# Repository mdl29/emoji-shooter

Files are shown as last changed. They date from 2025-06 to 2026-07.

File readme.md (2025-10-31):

# Emoji Shooter

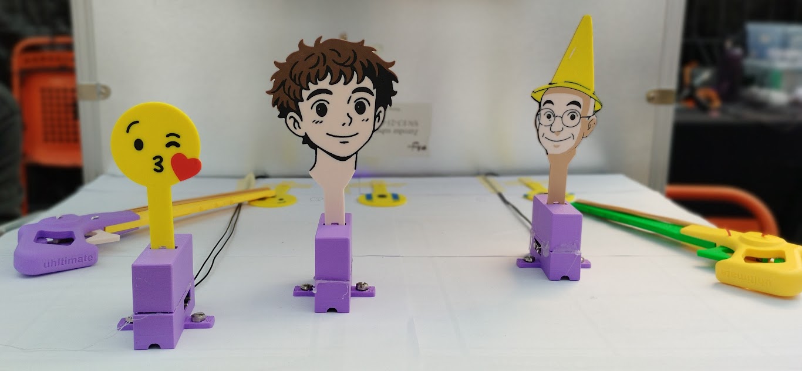
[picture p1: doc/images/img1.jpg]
Image of three targets


## Description
Emoji Shooter is an interactive shooting game. Players use a rubber band gun to shoot at jumping emoji targets. Each target is equipped with a mechanical switch for hit detection, and the game is tracked by an Arduino Uno. A web frontend displays the score and interacts with the hardware via serial communication.

## Features
- Physical emoji targets with mechanical hit detection
- Arduino firmware for real-time target state tracking
- Web frontend for score display and serial connection
- Visual feedback via LEDs on each target base

## Inspirations
- [Rubber Band Gun Model](https://makerworld.com/en/models/56969)
- [Original Jumping Targets](https://www.thingiverse.com/thing:1306585)

## How does it work?
Each emoji target sits on a base with a mechanical switch. When upright, the target presses the switch. A successful hit causes the target to jump or fall, releasing the switch. The Arduino detects this change and updates the game state.

### Sequence:
1. Target is placed upright, pressing the switch.
2. Player shoots a rubber band at the target.
3. Target jumps, releasing the switch.
4. Arduino detects the switch state change and registers a hit.
5. Score is sent to the web frontend and updated.

## Usage

1. Flash the firmware to your Arduino
2. Connect the Arduino to your computer via USB
3. Open the [website](https://mdl29.github.io/emoji-shooter/) in a Chromium browser
4. Connect to the Arduino with the button on top-left
5. Play by shooting at the emoji targets and watch your score update in real time

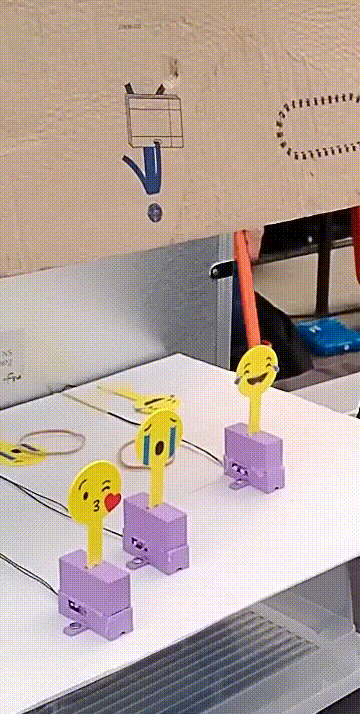
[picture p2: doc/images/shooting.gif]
Demo of a target being shot


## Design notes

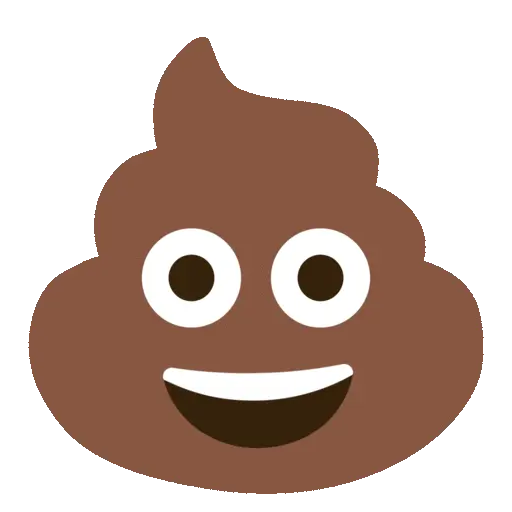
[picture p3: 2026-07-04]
frontend/asset/targets/poop.webp

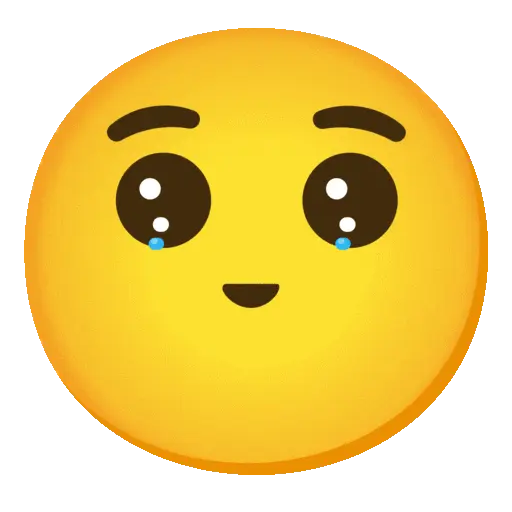
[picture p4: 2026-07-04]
frontend/asset/targets/cry.webp

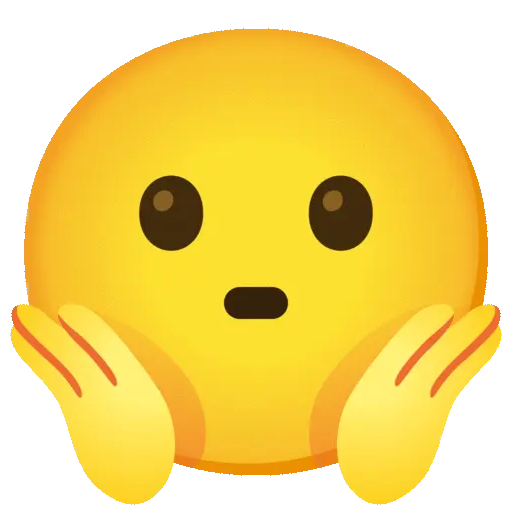
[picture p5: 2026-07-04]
frontend/asset/targets/chocked.webp

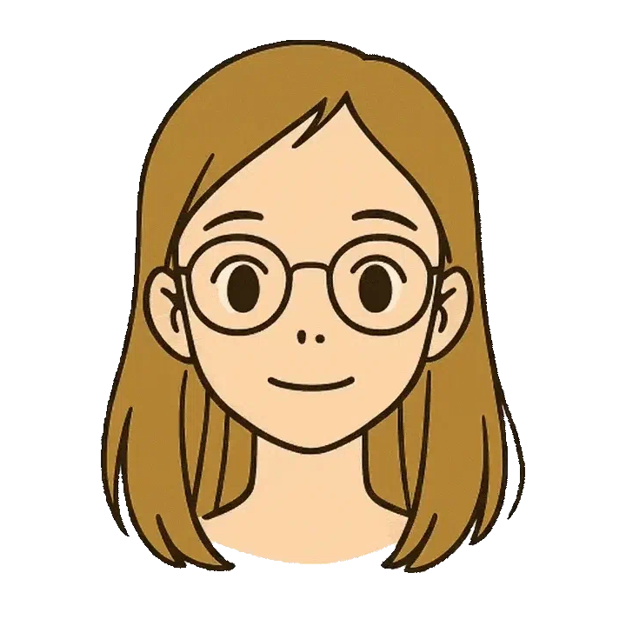
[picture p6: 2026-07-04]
frontend/asset/targets/erell.webp

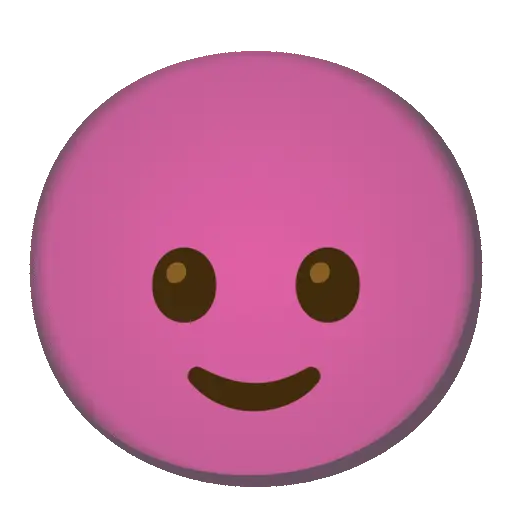
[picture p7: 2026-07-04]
frontend/asset/targets/devil.webp

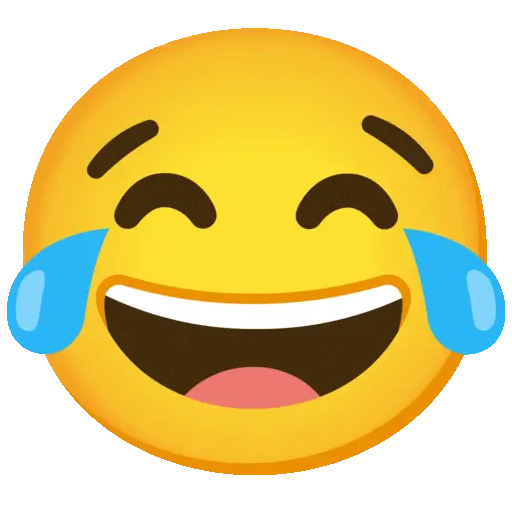
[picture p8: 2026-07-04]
frontend/asset/targets/laugh.webp

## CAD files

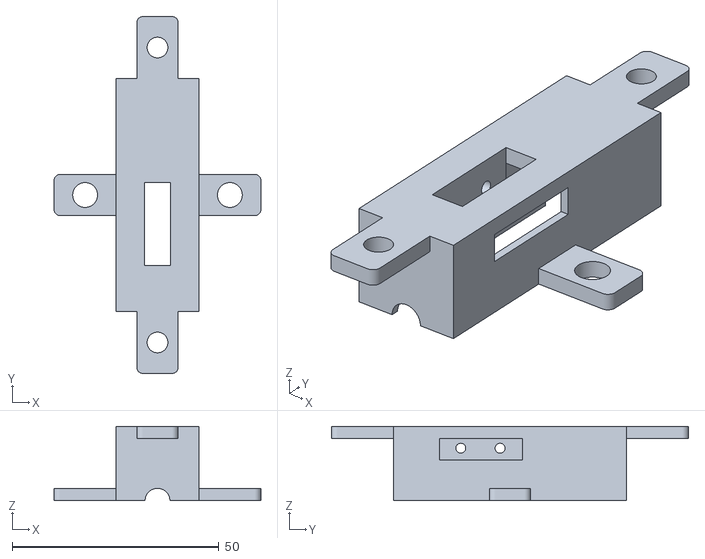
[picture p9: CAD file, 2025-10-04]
3Dparts/bottom-target-jump-base-Body - b3e90a6.stl
50.0 x 86.3 x 18.0

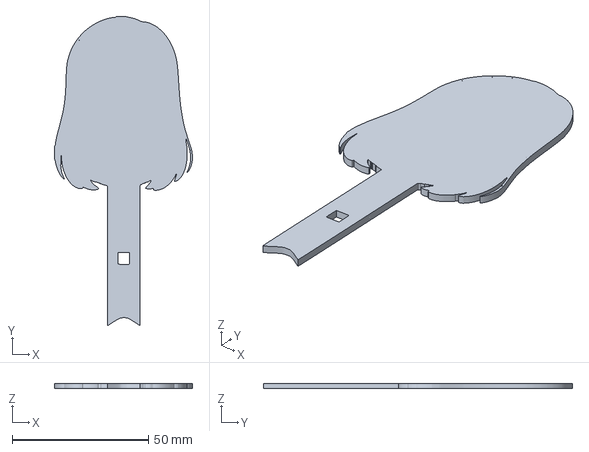
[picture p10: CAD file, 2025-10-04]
3Dparts/targets/3MF/Erell.3mf
50.9 x 113.6 x 2.00 mm

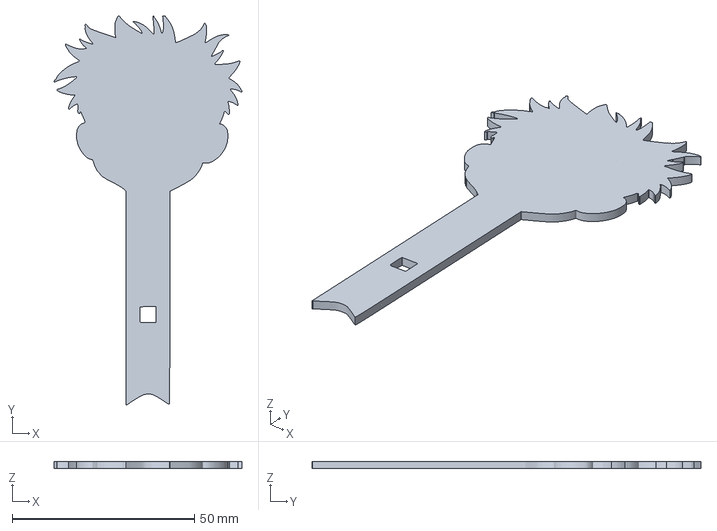
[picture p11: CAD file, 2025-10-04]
3Dparts/targets/3MF/Thibault.3mf
51.5 x 106.7 x 2.00 mm

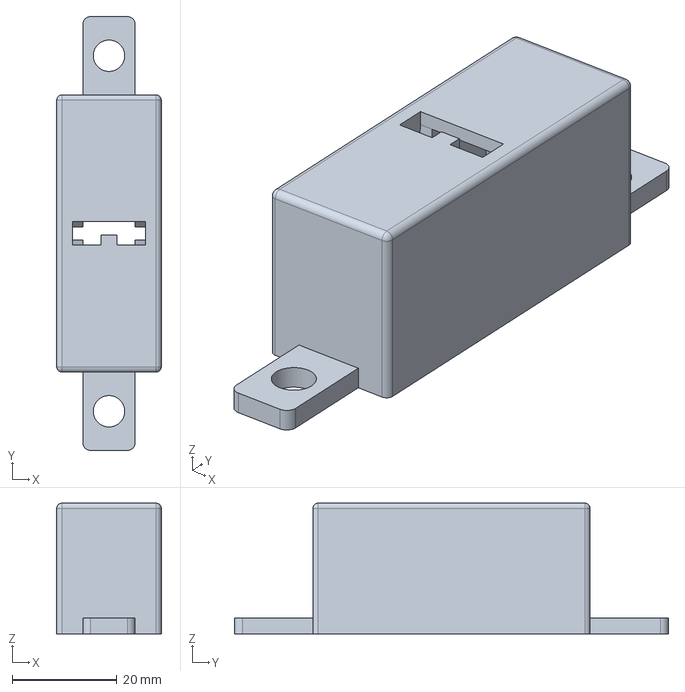
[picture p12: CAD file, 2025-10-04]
3Dparts/top-target-jump-base.FCStd
20.0 x 83.0 x 25.0 mm

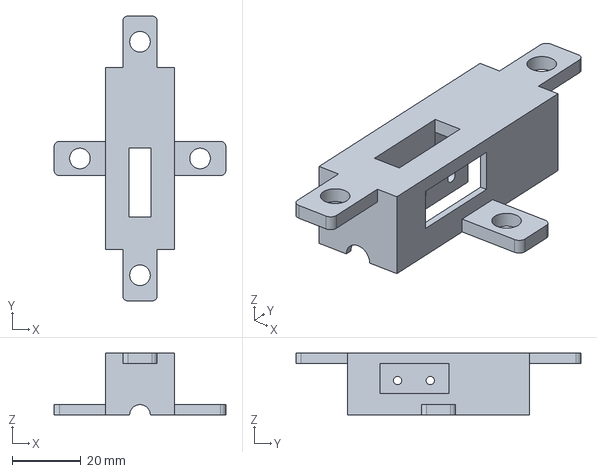
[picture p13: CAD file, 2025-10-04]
3Dparts/bottom-target-jump-base.FCStd
50.0 x 83.0 x 18.0 mm

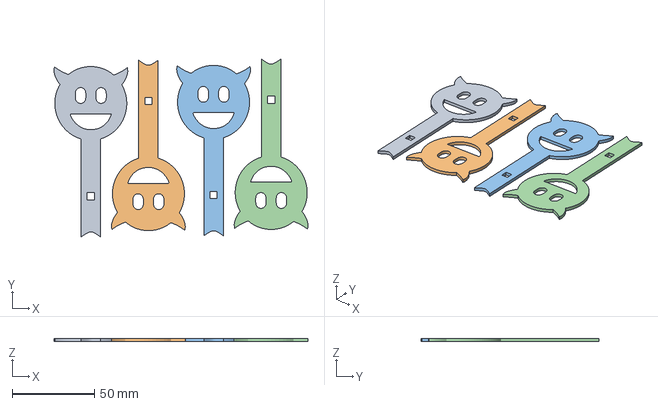
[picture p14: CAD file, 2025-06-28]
3Dparts/targets/3MF/Jumping Target - Devil - c0f72cd.3mf
154.7 x 108.3 x 2.00 mm
Jumping Target - Devil - c0f72cd.3mf x 4

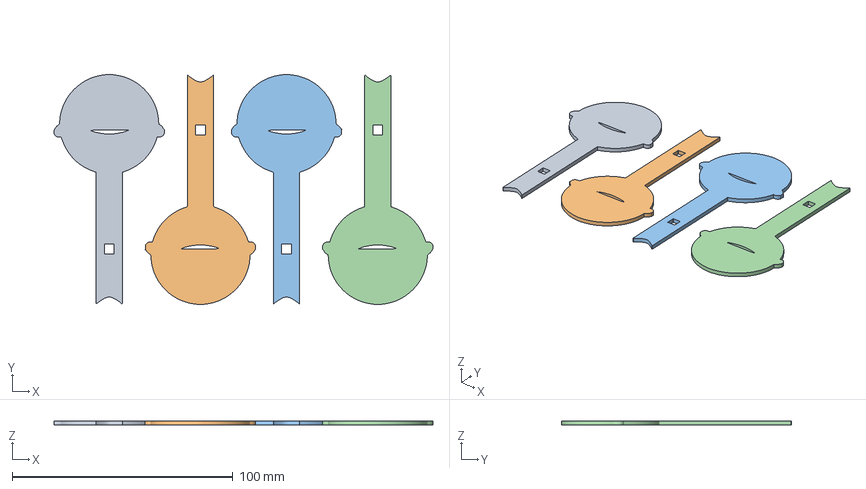
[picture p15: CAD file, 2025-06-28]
3Dparts/targets/3MF/Jumping Target - Laught 3644a9c.3mf
171.6 x 104.1 x 2.00 mm
Jumping Target - Laught 3644a9c.3mf x 4

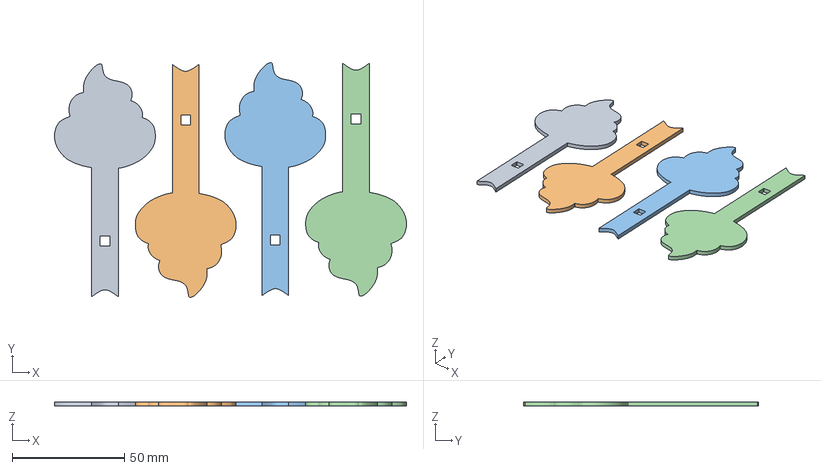
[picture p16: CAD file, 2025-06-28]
3Dparts/targets/3MF/Jumping Target - Poo c0f72cd.3mf
157.0 x 104.6 x 2.00 mm
Jumping Target - Poo c0f72cd.3mf x 4

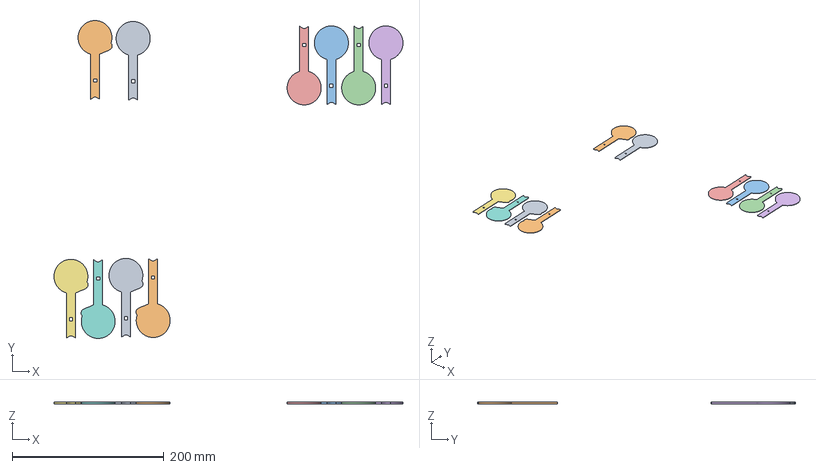
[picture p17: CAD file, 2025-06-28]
3Dparts/targets/3MF/Jumping Target - Cry & Kiss - c0f72cd.3mf
460.1 x 419.1 x 2.00 mm
Jumping Target - Cry - c0f72cd.3mf x 5
Jumping Target - Kiss - c0f72cd.3mf x 5

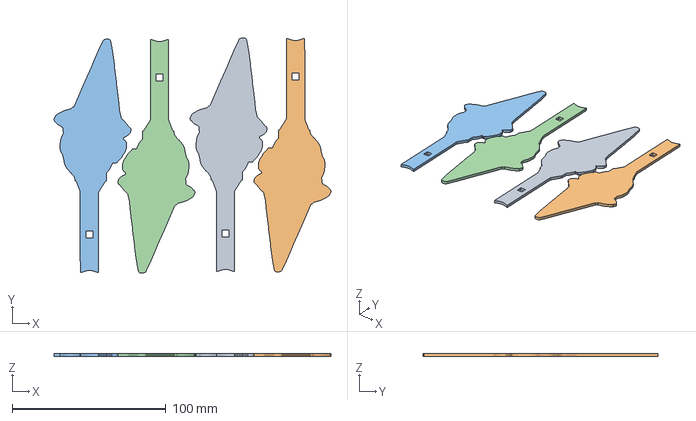
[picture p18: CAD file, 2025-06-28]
3Dparts/targets/3MF/Jumping Target - Christian Head a27d214.3mf
180.1 x 152.7 x 2.00 mm
Jumping Target - Christian Head a27d214.3mf x 4

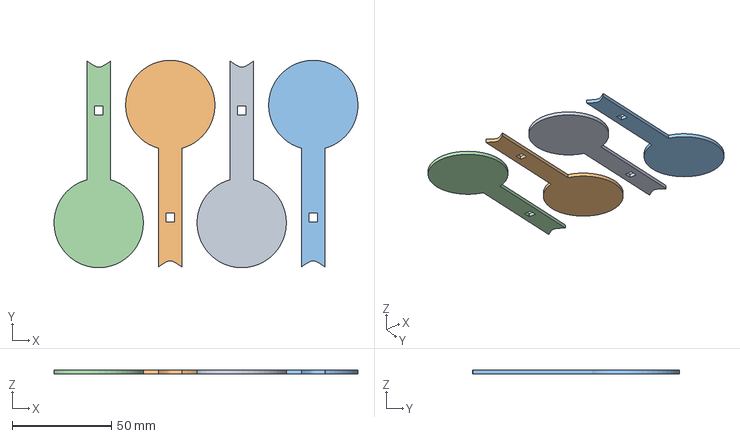
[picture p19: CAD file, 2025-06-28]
3Dparts/targets/3MF/Jumping Target - 4 x Chocked - c0f72cd.3mf
152.9 x 104.3 x 2.00 mm
Jumping Target - Chocked - c0f72cd.3mf x 4

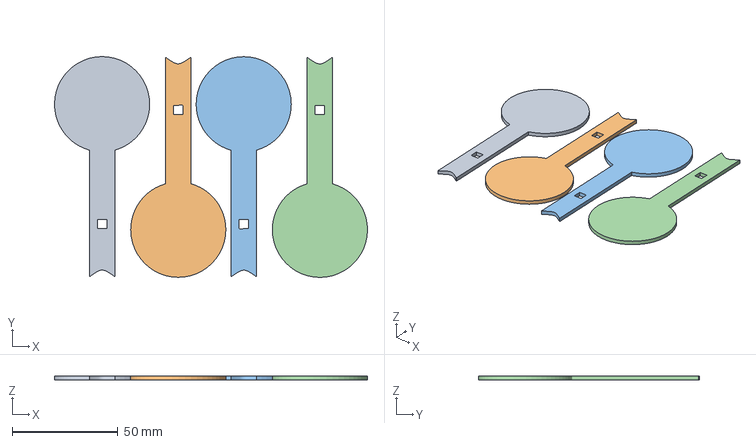
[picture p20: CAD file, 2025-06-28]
3Dparts/targets/3MF/Jumping Target - Chocked - c0f72cd.3mf
147.9 x 104.3 x 2.00 mm
Jumping Target - Chocked - c0f72cd.3mf x 4

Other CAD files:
3Dparts/top-target-jump-base - 442ed01.stl
3Dparts/bottom-target-jump-base.stl
3Dparts/top-target-jump-base.stl

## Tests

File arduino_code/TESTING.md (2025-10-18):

# Testing LED Blink Feature

## Feature Description
When the character 'f' is sent to the Arduino via serial communication, all LEDs will blink in sync:
- All LEDs turn HIGH for 100ms
- All LEDs turn LOW for 100ms
- LEDs return to their normal state (based on target switch states)

## Testing Methods

### Method 1: Using Arduino IDE Serial Monitor
1. Upload the sketch to your Arduino board
2. Open Tools > Serial Monitor in Arduino IDE
3. Set the baud rate to 9600
4. Type 'f' in the input field and click Send
5. Observe all LEDs blinking in sync (HIGH 100ms, LOW 100ms)

### Method 2: Using Serial Terminal (Linux/Mac)
```bash
# Find your Arduino port
ls /dev/tty*

# Send 'f' command (without newline)
echo -n "f" > /dev/ttyACM0  # Replace with your actual port
```

### Method 3: Using Python
```python
import serial
import time

# Open serial connection
ser = serial.Serial('/dev/ttyACM0', 9600)  # Replace with your port
time.sleep(2)  # Wait for Arduino to reset

# Send 'f' command
ser.write(b'f')

# Close connection
ser.close()
```

## Expected Behavior
- All 6 LEDs (pins 8-13) should turn ON simultaneously
- After 100ms, all LEDs should turn OFF simultaneously
- After another 100ms, each LED returns to its normal state (reflecting the target switch state)
- The entire sequence takes 200ms
- Normal target detection continues to work after the blink

## Integration with Game
The frontend application can be enhanced to send the 'f' command when the game finishes (all targets hit). This would require adding serial write capability to the JavaScript code.

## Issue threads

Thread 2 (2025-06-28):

:bricks: [Base-Target] Fix bottom to top "base jump target" with screws

Benvii, 2025-06-28:
[Base-Target] Fix bottom to top "base jump target" with screws

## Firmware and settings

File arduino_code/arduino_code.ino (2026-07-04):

class Target {
public:
  int pin;
  int id;
  int led;

  bool lastState;

  Target(int inputPin, int targetId, int ledPin) {
    pin = inputPin;
    id = targetId;
    led = ledPin;
  }

  void init() {
    pinMode(led, OUTPUT);
    pinMode(pin, INPUT_PULLUP);

    lastState = digitalRead(pin);
    setLED(lastState);
  }

  bool getState() { return digitalRead(pin); }

  void setLED(bool state) {
    // Revert LED state because
    // True  = no target
    // False = target down

    digitalWrite(led, !state);
  }

  void emit() {
    // Run every cycle
    // Change led state depending on input

    bool curState = getState();
    setLED(curState);
    if (curState != lastState) {
      lastState = curState;
      printState();

      delay(50);
    }
  }

  void printState() {
    if (lastState) {
      Serial.print("up:");
    } else {
      Serial.print("down:");
    }

    Serial.println(id);
  }
};

Target targets[] = {
  Target(2, 1, 8),
  Target(3, 2, 9),
  Target(4, 3, 10),
  Target(5, 4, 11),
  Target(6, 5, 12),
  Target(7, 6, 13)
};

void blinkAllLEDs() {
  // Blink all LEDs in sync: HIGH 100ms, LOW 100ms for 20 cycles
  for (int cycle = 0; cycle < 20; cycle++) {
    for (auto &target : targets) {
      digitalWrite(target.led, HIGH);
    }
    delay(100);

    for (auto &target : targets) {
      digitalWrite(target.led, LOW);
    }
    delay(100);
  }
}

void setup() {
  Serial.begin(9600);
  Serial.println("debug:starting");

  for (auto &target : targets) {
    target.init();
  }
}

void loop() {
  // Check for serial input
  if (Serial.available() > 0) {
    char incomingChar = Serial.read();
    if (incomingChar == "effects:fireworks") {
      blinkAllLEDs();
      // Clear any remaining characters in the buffer
      while (Serial.available() > 0) {
        Serial.read();
      }
    }
  }

  for (auto &target : targets) {
    target.emit();
  }
}

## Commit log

2025-06-28 :bricks: [targets] Target faces (SVG and m3f files)
    [Jumping Target - 4 x Chocked - c0f72cd.3mf, Jumping Target - Chocked - c0f72cd.3mf, Jumping Target - Christian Head a27d214.3mf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]
2025-10-04 🎨 [Target Faces] - Adding Erell & Thibault.
    * SVG
    * 3MF
    [Erell.3mf, Thibault.3mf]
2025-10-04 :bricks: [Base-Target] Fix bottom to top "base jump target" with screws (#3)
    * :bricks: [Base-Target] Fix bottom to top base jump target with screws. Fixes #2
    * :bricks: [Base-Target] Base with less constraint
    * upper part
    * :bricks: [Top-Target] Top part add screw holes.
    * :bricks: [Top-Target] Commit printed proto version with revision.
    * :bug: Change bottom reduce size to 53
    * :bricks: [Base-Target] Hole correct size of 6mm
    * :bricks: [Base-Target] Hole correct size of 7.5mm from base, so 1.2mm lower from previous version
    * :bricks: [Base-Target] Hole correct size of 8mm from base
    * :bricks: [Base-Target] Switch at 9mm
    * :bricks: [Base-Target] Switch at 10mm
    * :bricks: [Top-Tar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
    [bottom-target-jump-base-Body - b3e90a6.stl, bottom-target-jump-base.FCStd, bottom-target-jump-base.stl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]
2025-10-04 🔥 Remove old project and add the draft frontend
2025-10-04 ✨ Add the random emoji feature
2025-10-04 fix arduino_code
2025-10-04 🎨 Add SVGs (#11)
    * 🎨 Add SVGs
    * 🗑️ Clean existing SVGs
    * ♻️ Lower case file
    * :wrench: Configure all target
    * 🐛 Default target
2025-10-05 Add frontend (#12)
    * add frontend connection
    * 🎨 Add SVGs (#11)
    * Init targets on setup
    * handle NaN
    * 🎨 New, cleaner frontend
    Make the frontend cleaner by putting the css into its own file. Make the game infinitly loop
    * reduce cooldown
    * fix wrong target staying
    ---------
    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
    [sketch_may27a.ino]
2025-10-18 fix led state (#14)
    * fix led state
    * Apply suggestion from @Benvii
    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
    [sketch_may27a.ino]
2025-10-18 Blink LED when game finished command is sent (#16)
    * Initial plan
    * Add LED blink functionality when 'f' command is received
    * Add testing documentation for LED blink feature
    * Clear serial buffer after processing 'f' command
    * Update TESTING.md to use echo -n for cleaner serial output
    * Send 'f' command from frontend when game finishes
    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
2025-10-31 Cleanup repo (#17)
    * Update README
    * Move files
    * Rename files
    * Fix deployment
    * Copilot suggestions
    * Move images to doc/images
    [arduino_code.ino]
2026-06-13 remake frontend (#19)
    * remake frontend
    * feat: add qrcode and more emojis
    * feat: remake in Svelte
    * fix: save config to localStorage
    * fix: restart button restart the game and not the config
    * fix: repare le workflow
    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
2026-07-04 New arduino code and animated emojis (#25)
    * feat: change le format du protocole
    * feat: add animated emojis
    * feat: add cricri gif
    * feat: add Erell animated emoji
    * fix: use clearer message for fireworks
    * feat: add defaults emojis to config
    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
    [arduino_code.ino]
2026-07-04 fix: refresh LED every cycle instead of only on state change (#33)
    c'est tout pt sinon jsp pk
    [arduino_code.ino]
